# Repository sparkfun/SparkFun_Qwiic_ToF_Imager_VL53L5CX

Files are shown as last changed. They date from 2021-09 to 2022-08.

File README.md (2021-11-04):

SparkFun Qwiic ToF Imager with VL53L5CX
========================================

SparkFun Qwiic ToF Imager with VL53L5CX

[*SparkFun Qwiic ToF Imager with VL53L5CX(SEN-18642)*](https://www.sparkfun.com/products/18642)

The SparkFun Qwiic ToF Imager is built around VL53L5CX from ST Electronics; a state of the art, Time-of-Flight (ToF), multizone ranging sensor enhancing the ST FlightSense product family. This chip integrates a SPAD array, physical infrared filters, and diffractive optical elements (DOE) to achieve the best ranging performance in various ambient lighting conditions with a range of cover glass materials. Utilizing our handy Qwiic system, no soldering is required to connect it to the rest of your system. However, we still have broken out 0.1"-spaced pins in case you prefer to use a breadboard.

Multizone distance measurements are possible up to 8x8 zones with a wide 63° diagonal FoV which can be reduced by software. Thanks to ST Histogram patented algorithms, the VL53L5CX is able to detect different objects within the FoV. The Histogram also provides immunity to cover glass crosstalk beyond 60 cm.

Ideal for 3D room mapping, obstacle detection for robotics, gesture recognition, IoT, laser-assisted autofocus, and AR/VR enhancement, the Qwiic connector on this sensor makes integration easy. 

SparkFun labored with love to create this code. Feel like supporting open source hardware? 
Buy a [breakout board](https://www.sparkfun.com/products/14722) from SparkFun!

Repository Contents
-------------------

* **/Documents** - Datasheet and User Manual
* **/Hardware** - Eagle design files (.brd, .sch)

Documentation
--------------
* **[Arduino Library](https://github.com/sparkfun/SparkFun_VL53L5CX_Arduino_Library)** - Library for reading distance in millimeters, signal rate, status, etc.
* **[Hookup Guide](https://learn.sparkfun.com/tutorials/qwiic-tof-imager---vl53l5cx-hookup-guide)** - Hookup guide for the Qwiic ToF Imager VL53L5CX

License Information
-------------------

This product is _**open source**_! 

Please review the LICENSE.md file for license information. 

If you have any questions or concerns on licensing, please contact techsupport@sparkfun.com.

Please use, reuse, and modify these files as you see fit. Please maintain attribution to SparkFun Electronics and release any derivative under the same license.

Distributed as-is; no warranty is given.

- Your friends at SparkFun.

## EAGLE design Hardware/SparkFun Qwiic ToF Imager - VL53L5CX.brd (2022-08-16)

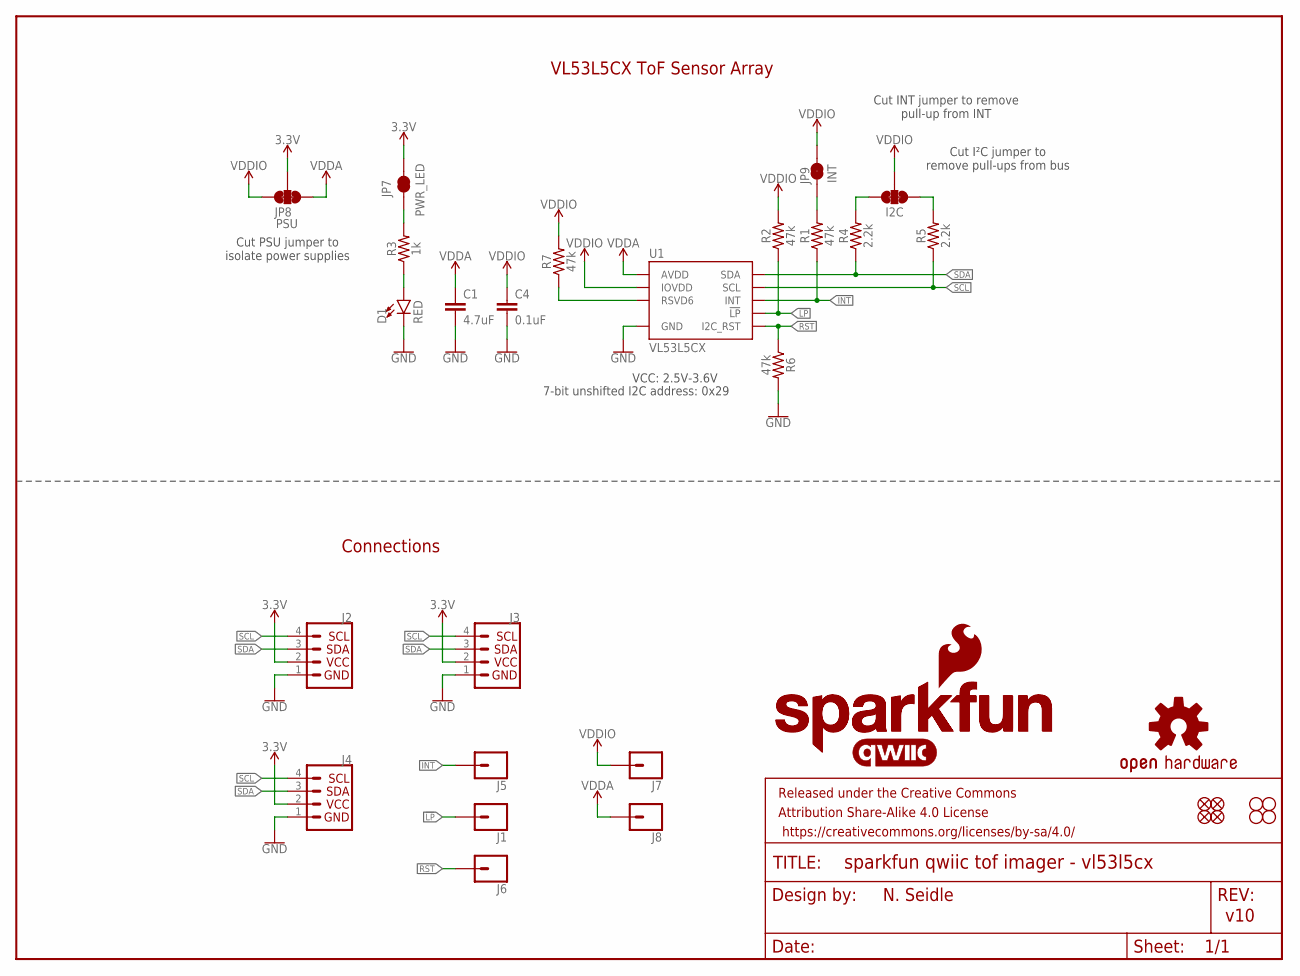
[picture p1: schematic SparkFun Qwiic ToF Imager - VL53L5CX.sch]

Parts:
C1: 4.7uF; 0603
C4: 0.1uF; 0603
D1: RED; LED-0603
FRAME1: FRAME-LETTER; CREATIVE_COMMONS
I2C: JUMPER-SMT_3_2-NC_TRACE_SILK; SMT-JUMPER_3_2-NC_TRACE_SILK
J1, J5, J6, J7, J8: CONN_01PTH_NO_SILK_YES_STOP; 1X01_NO_SILK
J2, J4: QWIIC_CONNECTORJS-1MM; JST04_1MM_RA
J3: PTH; 1X04_NO_SILK
JP1, JP2, JP5, JP6: FIDUCIALUFIDUCIAL; MICRO-FIDUCIAL
JP3, JP4, JP10, JP11: STAND-OFF
JP7: PWR_LED; SMT-JUMPER_2_NC_TRACE_SILK
JP8: PSU; SMT-JUMPER_3_2-NC_TRACE_SILK
JP9: INT; SMT-JUMPER_2_NC_TRACE_SILK
LOGO1: OSHW-LOGOMINI; OSHW-LOGO-MINI
LOGO3: QWIIC_LOGO_CONNECTOR; QWIIC_5.5MM
R1, R2, R6, R7: 47k; 0603
R3: 1k; 0603
R4, R5: 2.2k; 0603
U1: VL53L5CX
U$1: SFE_LOGO_NAME.1_INCH; SFE_LOGO_NAME_.1
U$2: SFE_LOGO_NAME_FLAME.1_INCH; SFE_LOGO_NAME_FLAME_.1

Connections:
3.3V: J2.2, J3.2 (VCC), J4.2, JP7.2, JP8.2
!LP: J1.1, R2.1, U1.A5 (!LP)
GND: C1.2, C4.2, D1.C, J2.1, J3.1 (GND), J4.1, R6.2, U1.A2 (GND), U1.A6 (GND), U1.A7 (GND), U1.B4 (GND), U1.C1 (GND), U1.C6 (GND), U1.C7 (GND)
INT: J5.1, R1.1, U1.A3 (INT)
unnamed: I2C.1, R5.2
unnamed: I2C.3, R4.2
unnamed: D1.A, R3.1
unnamed: JP9.1, R1.2
unnamed: JP7.1, R3.2
unnamed: R7.1, U1.C2 (RSVD6)
RST: J6.1, R6.1, U1.A1 (I2C_RST)
SCL: J2.4, J3.4 (SCL), J4.4, R5.1, U1.C4 (SCL)
SDA: J2.3, J3.3 (SDA), J4.3, R4.1, U1.C3 (SDA)
VDDA: C1.1, J8.1, JP8.1, U1.B1 (AVDD), U1.B7 (AVDD)
VDDIO: C4.1, I2C.2, J7.1, JP8.3, JP9.2, R2.2, R7.2, U1.A4 (IOVDD)

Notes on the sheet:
N. Seidle
v10
7-bit unshifted I2C address: 0x29
Cut I²C jumper to remove pull-ups from bus
Cut INT jumper to remove pull-up from INT
VCC: 2.5V-3.6V
VL53L5CX ToF Sensor Array
Cut PSU jumper to isolate power supplies
Connections

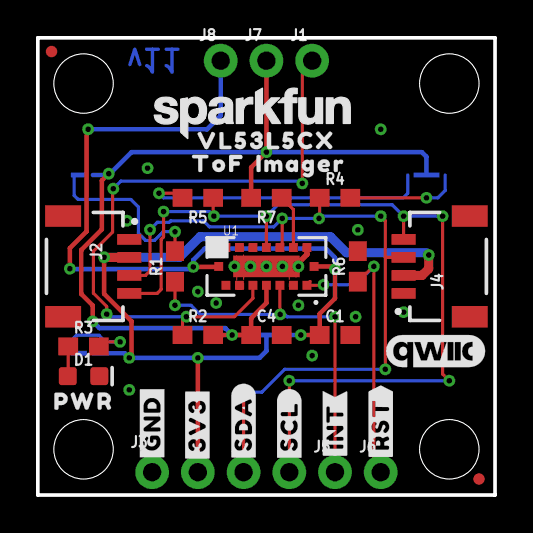
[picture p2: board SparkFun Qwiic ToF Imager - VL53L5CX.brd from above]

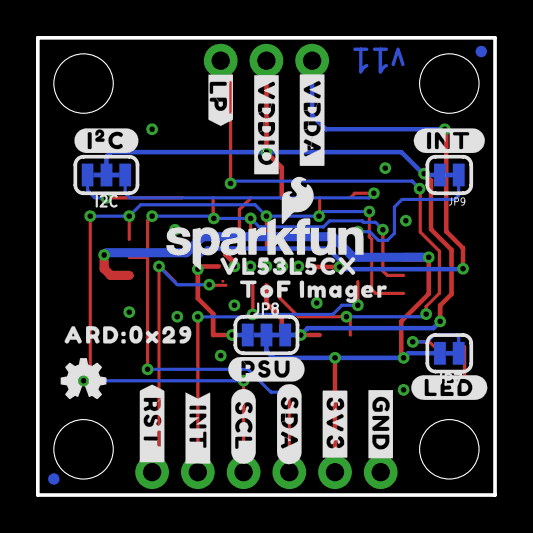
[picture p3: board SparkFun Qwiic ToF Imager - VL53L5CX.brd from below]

Board: 2 copper layers, 25.4 x 25.4 mm, 63 parts (25 on the bottom side), 15 nets.

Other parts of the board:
U$3, U$21: #3V3#13
U$4: PWR12
U$5: #LED#10
U$6: #INT#0
U$7: #RST#1
U$8: #INT_#0
U$9: #RST_#1
U$10: ##LP##2
U$11: #INT#1
U$12: #VDDA#0
U$14: #VDDIO#1
U$15: #PSU#0
U$16: #I�C#0
U$17, U$19: VL53L5CX0
U$18, U$22: IMAGER2
U$20, U$23: TOF1
U$24: #SCL#1
U$25: #SDA#0
U$26, U$30: #GND#62130
U$27: ARD#0X290
U$28: #SDA#62131
U$29: #SCL#62132

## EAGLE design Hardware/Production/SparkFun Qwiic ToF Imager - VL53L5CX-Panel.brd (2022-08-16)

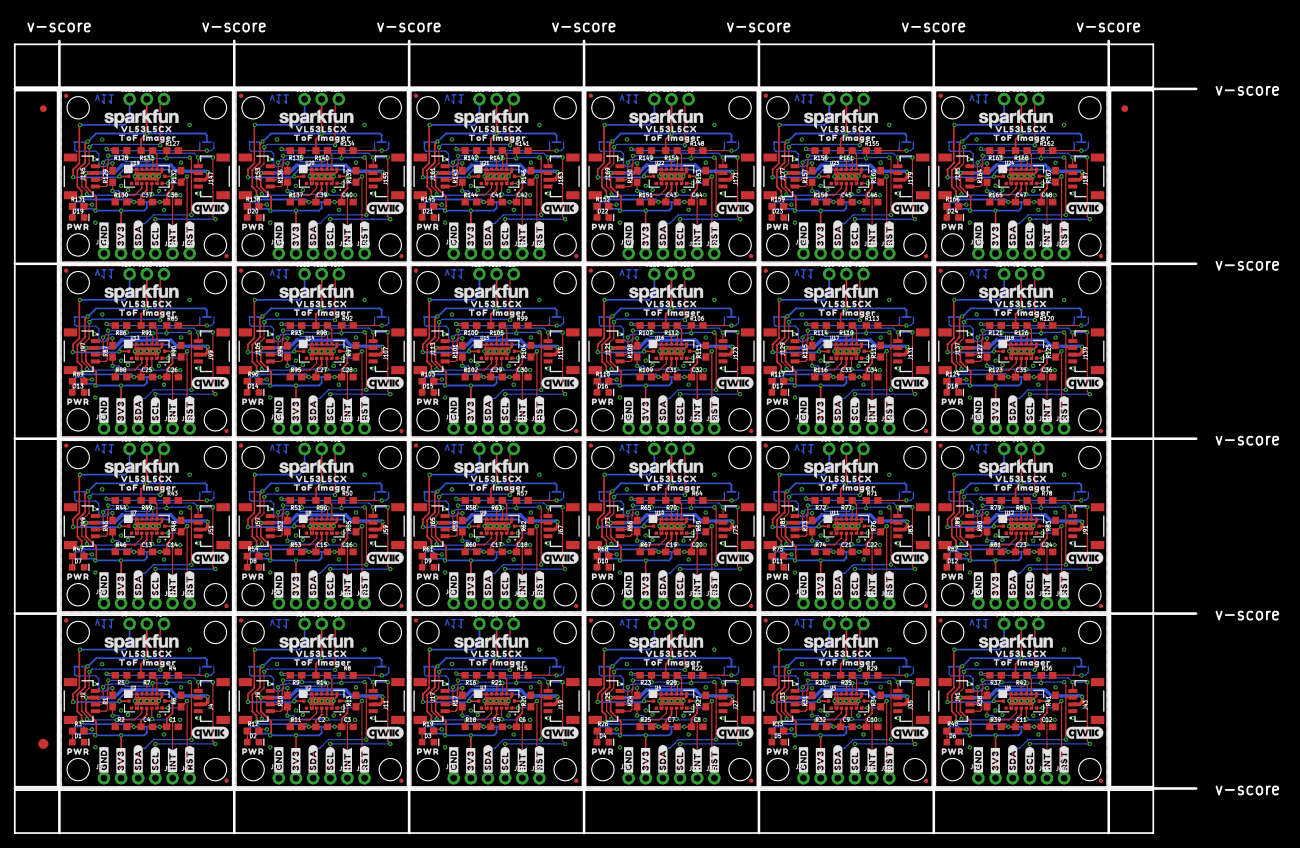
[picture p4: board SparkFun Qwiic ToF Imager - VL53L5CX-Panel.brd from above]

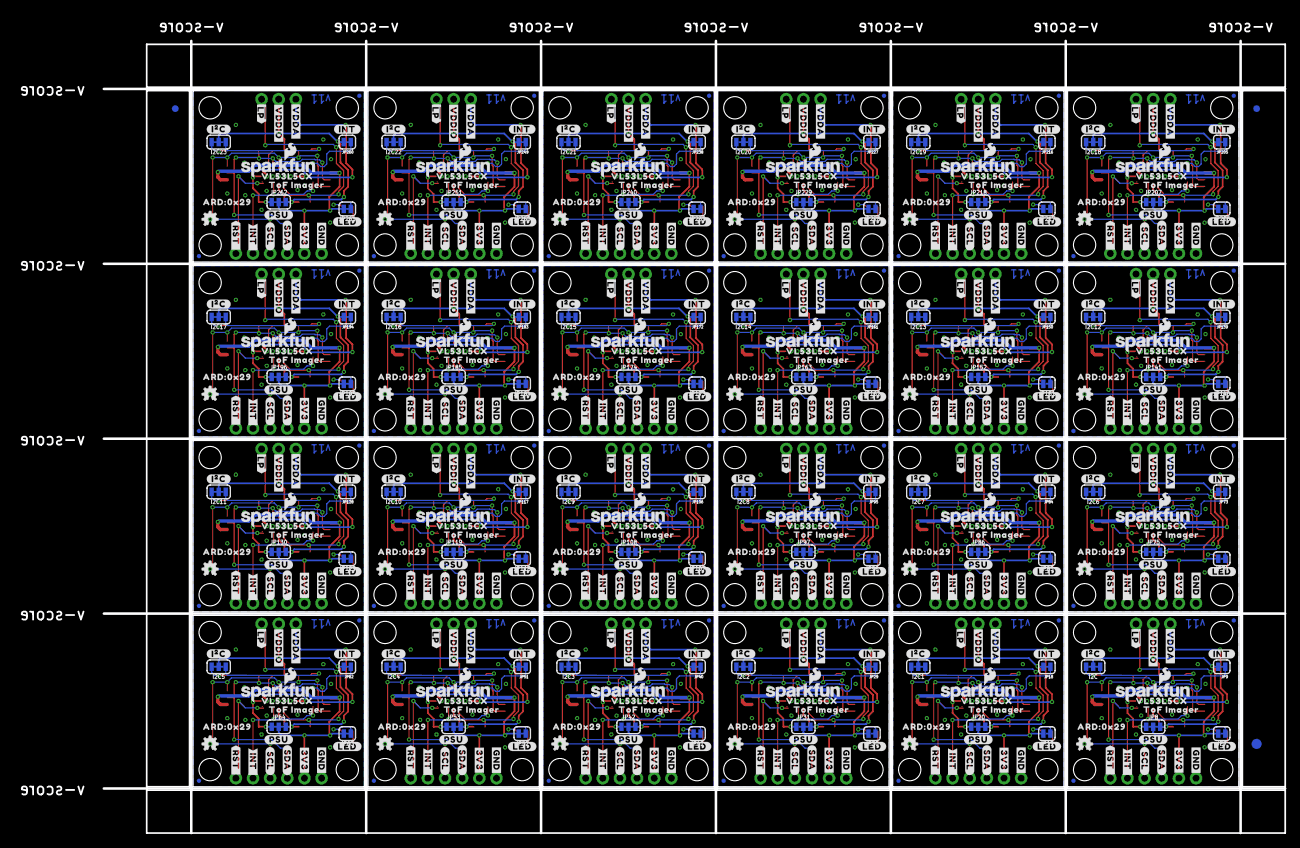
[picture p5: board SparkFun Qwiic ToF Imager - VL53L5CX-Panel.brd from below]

Board: 2 copper layers, 175.0 x 117.3 mm, 1494 parts (603 on the bottom side), 360 nets.

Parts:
C1, C3, C6, C8, C10, C12, C14, C16, C18, C20, C22, C24, C26, C28, C30, C32, C34, C36, C38, C40, C42, C44, C46, C48: 4.7uF; 0603
C2, C4, C5, C7, C9, C11, C13, C15, C17, C19, C21, C23, C25, C27, C29, C31, C33, C35, C37, C39, C41, C43, C45, C47: 0.1uF; 0603
D1, D2, D3, D4, D5, D6, D7, D8, D9, D10, D11, D12, D13, D14, D15, D16, D17, D18, D19, D20, D21, D22, D23, D24: RED; LED-0603
E$1, E$2, E$3, E$4: FIDUCIAL-1X2
E$5, E$6: FIDUCIAL-1.5X3
I2C, I2C1, I2C2, I2C3, I2C4, I2C5, I2C6, I2C7, I2C8, I2C9, I2C10, I2C11, I2C12, I2C13, I2C14, I2C15, I2C16, I2C17, I2C18, I2C19, I2C20, I2C21, I2C22, I2C23: JUMPER-SMT_3_2-NC_TRACE_SILK; SMT-JUMPER_3_2-NC_TRACE_SILK
J1, J5, J6, J7, J8, J12, J13, J14, J15, J16, J20, J21, J22, J23, J24, J28, J29, J30, J31, J32, J36, J37, J38, J39, J40, J44, J45, J46, J47, J48, J52, J53, J54, J55, J56, J60, J61, J62, J63, J64, J68, J69, J70, J71, J72, J76, J77, J78, J79, J80, J84, J85, J86, J87, J88, J92, J93, J94, J95, J96, J100, J101, J102, J103, J104, J108, J109, J110, J111, J112, J116, J117, J118, J119, J120, J124, J125, J126, J127, J128, J132, J133, J134, J135, J136, J140, J141, J142, J143, J144, J148, J149, J150, J151, J152, J156, J157, J158, J159, J160, J164, J165, J166, J167, J168, J172, J173, J174, J175, J176, J180, J181, J182, J183, J184, J188, J189, J190, J191, J192: 1X01_NO_SILK
J2, J4, J9, J11, J17, J19, J25, J27, J33, J35, J41, J43, J49, J51, J57, J59, J65, J67, J73, J75, J81, J83, J89, J91, J97, J99, J105, J107, J113, J115, J121, J123, J129, J131, J137, J139, J145, J147, J153, J155, J161, J163, J169, J171, J177, J179, J185, J187: JST04_1MM_RA
J3, J10, J18, J26, J34, J42, J50, J58, J66, J74, J82, J90, J98, J106, J114, J122, J130, J138, J146, J154, J162, J170, J178, J186: PTH; 1X04_NO_SILK
JP1, JP2, JP5, JP6, JP14, JP15, JP16, JP17, JP25, JP26, JP27, JP28, JP36, JP37, JP38, JP39, JP47, JP48, JP49, JP50, JP58, JP59, JP60, JP61, JP69, JP70, JP71, JP72, JP80, JP81, JP82, JP83, JP91, JP92, JP93, JP94, JP102, JP103, JP104, JP105, JP113, JP114, JP115, JP116, JP124, JP125, JP126, JP127, JP135, JP136, JP137, JP138, JP146, JP147, JP148, JP149, JP157, JP158, JP159, JP160, JP168, JP169, JP170, JP171, JP179, JP180, JP181, JP182, JP190, JP191, JP192, JP193, JP201, JP202, JP203, JP204, JP212, JP213, JP214, JP215, JP223, JP224, JP225, JP226, JP234, JP235, JP236, JP237, JP245, JP246, JP247, JP248, JP256, JP257, JP258, JP259: FIDUCIALUFIDUCIAL; MICRO-FIDUCIAL
JP3, JP4, JP10, JP11, JP12, JP13, JP21, JP22, JP23, JP24, JP32, JP33, JP34, JP35, JP43, JP44, JP45, JP46, JP54, JP55, JP56, JP57, JP65, JP66, JP67, JP68, JP76, JP77, JP78, JP79, JP87, JP88, JP89, JP90, JP98, JP99, JP100, JP101, JP109, JP110, JP111, JP112, JP120, JP121, JP122, JP123, JP131, JP132, JP133, JP134, JP142, JP143, JP144, JP145, JP153, JP154, JP155, JP156, JP164, JP165, JP166, JP167, JP175, JP176, JP177, JP178, JP186, JP187, JP188, JP189, JP197, JP198, JP199, JP200, JP208, JP209, JP210, JP211, JP219, JP220, JP221, JP222, JP230, JP231, JP232, JP233, JP241, JP242, JP243, JP244, JP252, JP253, JP254, JP255, JP263, JP264: STAND-OFF
JP7, JP19, JP30, JP41, JP52, JP63, JP74, JP85, JP96, JP107, JP118, JP129, JP140, JP151, JP162, JP173, JP184, JP195, JP206, JP217, JP228, JP239, JP250, JP261: PWR_LED; SMT-JUMPER_2_NC_TRACE_SILK
JP8, JP20, JP31, JP42, JP53, JP64, JP75, JP86, JP97, JP108, JP119, JP130, JP141, JP152, JP163, JP174, JP185, JP196, JP207, JP218, JP229, JP240, JP251, JP262: PSU; SMT-JUMPER_3_2-NC_TRACE_SILK
JP9, JP18, JP29, JP40, JP51, JP62, JP73, JP84, JP95, JP106, JP117, JP128, JP139, JP150, JP161, JP172, JP183, JP194, JP205, JP216, JP227, JP238, JP249, JP260: INT; SMT-JUMPER_2_NC_TRACE_SILK
LOGO1, LOGO2, LOGO5, LOGO7, LOGO9, LOGO11, LOGO13, LOGO15, LOGO17, LOGO19, LOGO21, LOGO23, LOGO25, LOGO27, LOGO29, LOGO31, LOGO33, LOGO35, LOGO37, LOGO39, LOGO41, LOGO43, LOGO45, LOGO47: OSHW-LOGOMINI; OSHW-LOGO-MINI
LOGO3, LOGO4, LOGO6, LOGO8, LOGO10, LOGO12, LOGO14, LOGO16, LOGO18, LOGO20, LOGO22, LOGO24, LOGO26, LOGO28, LOGO30, LOGO32, LOGO34, LOGO36, LOGO38, LOGO40, LOGO42, LOGO44, LOGO46, LOGO48: QWIIC_LOGO_CONNECTOR; QWIIC_5.5MM
R1, R2, R6, R7, R10, R11, R13, R14, R17, R18, R20, R21, R24, R25, R27, R28, R31, R32, R34, R35, R38, R39, R41, R42, R45, R46, R48, R49, R52, R53, R55, R56, R59, R60, R62, R63, R66, R67, R69, R70, R73, R74, R76, R77, R80, R81, R83, R84, R87, R88, R90, R91, R94, R95, R97, R98, R101, R102, R104, R105, R108, R109, R111, R112, R115, R116, R118, R119, R122, R123, R125, R126, R129, R130, R132, R133, R136, R137, R139, R140, R143, R144, R146, R147, R150, R151, R153, R154, R157, R158, R160, R161, R164, R165, R167, R168: 47k; 0603
R3, R12, R19, R26, R33, R40, R47, R54, R61, R68, R75, R82, R89, R96, R103, R110, R117, R124, R131, R138, R145, R152, R159, R166: 1k; 0603
R4, R5, R8, R9, R15, R16, R22, R23, R29, R30, R36, R37, R43, R44, R50, R51, R57, R58, R64, R65, R71, R72, R78, R79, R85, R86, R92, R93, R99, R100, R106, R107, R113, R114, R120, R121, R127, R128, R134, R135, R141, R142, R148, R149, R155, R156, R162, R163: 2.2k; 0603
U1, U2, U3, U4, U5, U6, U7, U8, U9, U10, U11, U12, U13, U14, U15, U16, U17, U18, U19, U20, U21, U22, U23, U24: VL53L5CX
U$1, U$31, U$60, U$89, U$118, U$147, U$176, U$205, U$234, U$263, U$292, U$321, U$350, U$379, U$408, U$437, U$466, U$495, U$524, U$553, U$582, U$611, U$640, U$669: SFE_LOGO_NAME.1_INCH; SFE_LOGO_NAME_.1
U$2, U$13, U$59, U$88, U$117, U$146, U$175, U$204, U$233, U$262, U$291, U$320, U$349, U$378, U$407, U$436, U$465, U$494, U$523, U$552, U$581, U$610, U$639, U$668: SFE_LOGO_NAME_FLAME.1_INCH; SFE_LOGO_NAME_FLAME_.1
U$3, U$21, U$36, U$37, U$65, U$66, U$94, U$95, U$123, U$124, U$152, U$153, U$181, U$182, U$210, U$211, U$239, U$240, U$268, U$269, U$297, U$298, U$326, U$327, U$355, U$356, U$384, U$385, U$413, U$414, U$442, U$443, U$471, U$472, U$500, U$501, U$529, U$530, U$558, U$559, U$587, U$588, U$616, U$617, U$645, U$646, U$674, U$675: #3V3#13
U$4, U$38, U$67, U$96, U$125, U$154, U$183, U$212, U$241, U$270, U$299, U$328, U$357, U$386, U$415, U$444, U$473, U$502, U$531, U$560, U$589, U$618, U$647, U$676: PWR12
U$5, U$39, U$68, U$97, U$126, U$155, U$184, U$213, U$242, U$271, U$300, U$329, U$358, U$387, U$416, U$445, U$474, U$503, U$532, U$561, U$590, U$619, U$648, U$677: #LED#10
U$6, U$40, U$69, U$98, U$127, U$156, U$185, U$214, U$243, U$272, U$301, U$330, U$359, U$388, U$417, U$446, U$475, U$504, U$533, U$562, U$591, U$620, U$649, U$678: #INT#0
U$7, U$41, U$70, U$99, U$128, U$157, U$186, U$215, U$244, U$273, U$302, U$331, U$360, U$389, U$418, U$447, U$476, U$505, U$534, U$563, U$592, U$621, U$650, U$679: #RST#1
U$8, U$42, U$71, U$100, U$129, U$158, U$187, U$216, U$245, U$274, U$303, U$332, U$361, U$390, U$419, U$448, U$477, U$506, U$535, U$564, U$593, U$622, U$651, U$680: #INT_#0
U$9, U$43, U$72, U$101, U$130, U$159, U$188, U$217, U$246, U$275, U$304, U$333, U$362, U$391, U$420, U$449, U$478, U$507, U$536, U$565, U$594, U$623, U$652, U$681: #RST_#1
U$10, U$44, U$73, U$102, U$131, U$160, U$189, U$218, U$247, U$276, U$305, U$334, U$363, U$392, U$421, U$450, U$479, U$508, U$537, U$566, U$595, U$624, U$653, U$682: ##LP##2
U$11, U$51, U$80, U$109, U$138, U$167, U$196, U$225, U$254, U$283, U$312, U$341, U$370, U$399, U$428, U$457, U$486, U$515, U$544, U$573, U$602, U$631, U$660, U$689: #INT#1
U$12, U$45, U$74, U$103, U$132, U$161, U$190, U$219, U$248, U$277, U$306, U$335, U$364, U$393, U$422, U$451, U$480, U$509, U$538, U$567, U$596, U$625, U$654, U$683: #VDDA#0
U$14, U$46, U$75, U$104, U$133, U$162, U$191, U$220, U$249, U$278, U$307, U$336, U$365, U$394, U$423, U$452, U$481, U$510, U$539, U$568, U$597, U$626, U$655, U$684: #VDDIO#1
U$15, U$52, U$81, U$110, U$139, U$168, U$197, U$226, U$255, U$284, U$313, U$342, U$371, U$400, U$429, U$458, U$487, U$516, U$545, U$574, U$603, U$632, U$661, U$690: #PSU#0
U$16, U$50, U$79, U$108, U$137, U$166, U$195, U$224, U$253, U$282, U$311, U$340, U$369, U$398, U$427, U$456, U$485, U$514, U$543, U$572, U$601, U$630, U$659, U$688: #I�C#0
U$17, U$19, U$47, U$53, U$76, U$82, U$105, U$111, U$134, U$140, U$163, U$169, U$192, U$198, U$221, U$227, U$250, U$256, U$279, U$285, U$308, U$314, U$337, U$343, U$366, U$372, U$395, U$401, U$424, U$430, U$453, U$459, U$482, U$488, U$511, U$517, U$540, U$546, U$569, U$575, U$598, U$604, U$627, U$633, U$656, U$662, U$685, U$691: VL53L5CX0
U$18, U$22, U$48, U$55, U$77, U$84, U$106, U$113, U$135, U$142, U$164, U$171, U$193, U$200, U$222, U$229, U$251, U$258, U$280, U$287, U$309, U$316, U$338, U$345, U$367, U$374, U$396, U$403, U$425, U$432, U$454, U$461, U$483, U$490, U$512, U$519, U$541, U$548, U$570, U$577, U$599, U$606, U$628, U$635, U$657, U$664, U$686, U$693: IMAGER2
U$20, U$23, U$49, U$54, U$78, U$83, U$107, U$112, U$136, U$141, U$165, U$170, U$194, U$199, U$223, U$228, U$252, U$257, U$281, U$286, U$310, U$315, U$339, U$344, U$368, U$373, U$397, U$402, U$426, U$431, U$455, U$460, U$484, U$489, U$513, U$518, U$542, U$547, U$571, U$576, U$600, U$605, U$629, U$634, U$658, U$663, U$687, U$692: TOF1
U$24, U$56, U$85, U$114, U$143, U$172, U$201, U$230, U$259, U$288, U$317, U$346, U$375, U$404, U$433, U$462, U$491, U$520, U$549, U$578, U$607, U$636, U$665, U$694: #SCL#1
U$25, U$57, U$86, U$115, U$144, U$173, U$202, U$231, U$260, U$289, U$318, U$347, U$376, U$405, U$434, U$463, U$492, U$521, U$550, U$579, U$608, U$637, U$666, U$695: #SDA#0
U$26, U$30, U$32, U$35, U$61, U$64, U$90, U$93, U$119, U$122, U$148, U$151, U$177, U$180, U$206, U$209, U$235, U$238, U$264, U$267, U$293, U$296, U$322, U$325, U$351, U$354, U$380, U$383, U$409, U$412, U$438, U$441, U$467, U$470, U$496, U$499, U$525, U$528, U$554, U$557, U$583, U$586, U$612, U$615, U$641, U$644, U$670, U$673: #GND#62130
U$27, U$58, U$87, U$116, U$145, U$174, U$203, U$232, U$261, U$290, U$319, U$348, U$377, U$406, U$435, U$464, U$493, U$522, U$551, U$580, U$609, U$638, U$667, U$696: ARD#0X290
U$28, U$33, U$62, U$91, U$120, U$149, U$178, U$207, U$236, U$265, U$294, U$323, U$352, U$381, U$410, U$439, U$468, U$497, U$526, U$555, U$584, U$613, U$642, U$671: #SDA#62131
U$29, U$34, U$63, U$92, U$121, U$150, U$179, U$208, U$237, U$266, U$295, U$324, U$353, U$382, U$411, U$440, U$469, U$498, U$527, U$556, U$585, U$614, U$643, U$672: #SCL#62132

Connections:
3.3V: J2.2, J3.2, J4.2, JP7.2, JP8.2
3.3V1: J9.2, J10.2, J11.2, JP19.2, JP20.2
3.3V2: J17.2, J18.2, J19.2, JP30.2, JP31.2
3.3V3: J25.2, J26.2, J27.2, JP41.2, JP42.2
3.3V4: J33.2, J34.2, J35.2, JP52.2, JP53.2
3.3V5: J41.2, J42.2, J43.2, JP63.2, JP64.2
3.3V6: J49.2, J50.2, J51.2, JP74.2, JP75.2
3.3V7: J57.2, J58.2, J59.2, JP85.2, JP86.2
3.3V8: J65.2, J66.2, J67.2, JP96.2, JP97.2
3.3V9: J73.2, J74.2, J75.2, JP107.2, JP108.2
3.3V10: J81.2, J82.2, J83.2, JP118.2, JP119.2
3.3V11: J89.2, J90.2, J91.2, JP129.2, JP130.2
3.3V12: J97.2, J98.2, J99.2, JP140.2, JP141.2
3.3V13: J105.2, J106.2, J107.2, JP151.2, JP152.2
3.3V14: J113.2, J114.2, J115.2, JP162.2, JP163.2
3.3V15: J121.2, J122.2, J123.2, JP173.2, JP174.2
3.3V16: J129.2, J130.2, J131.2, JP184.2, JP185.2
3.3V17: J137.2, J138.2, J139.2, JP195.2, JP196.2
3.3V18: J145.2, J146.2, J147.2, JP206.2, JP207.2
3.3V19: J153.2, J154.2, J155.2, JP217.2, JP218.2
3.3V20: J161.2, J162.2, J163.2, JP228.2, JP229.2
3.3V21: J169.2, J170.2, J171.2, JP239.2, JP240.2
3.3V22: J177.2, J178.2, J179.2, JP250.2, JP251.2
3.3V23: J185.2, J186.2, J187.2, JP261.2, JP262.2
!LP: J1.1, R2.1, U1.A5
!LP1: J13.1, R11.1, U2.A5
!LP2: J21.1, R18.1, U3.A5
!LP3: J29.1, R25.1, U4.A5
!LP4: J37.1, R32.1, U5.A5
!LP5: J45.1, R39.1, U6.A5
!LP6: J53.1, R46.1, U7.A5
!LP7: J61.1, R53.1, U8.A5
!LP8: J69.1, R60.1, U9.A5
!LP9: J77.1, R67.1, U10.A5
!LP10: J85.1, R74.1, U11.A5
!LP11: J93.1, R81.1, U12.A5
!LP12: J101.1, R88.1, U13.A5
!LP13: J109.1, R95.1, U14.A5
!LP14: J117.1, R102.1, U15.A5
!LP15: J125.1, R109.1, U16.A5
!LP16: J133.1, R116.1, U17.A5
!LP17: J141.1, R123.1, U18.A5
!LP18: J149.1, R130.1, U19.A5
!LP19: J157.1, R137.1, U20.A5
!LP20: J165.1, R144.1, U21.A5
!LP21: J173.1, R151.1, U22.A5
!LP22: J181.1, R158.1, U23.A5
!LP23: J189.1, R165.1, U24.A5
GND: C1.2, C4.2, D1.C, J2.1, J3.1, J4.1, R6.2, U1.A2, U1.A6, U1.A7, U1.B4, U1.C1, U1.C6, U1.C7
GND1: C2.2, C3.2, D2.C, J9.1, J10.1, J11.1, R13.2, U2.A2, U2.A6, U2.A7, U2.B4, U2.C1, U2.C6, U2.C7
GND2: C5.2, C6.2, D3.C, J17.1, J18.1, J19.1, R20.2, U3.A2, U3.A6, U3.A7, U3.B4, U3.C1, U3.C6, U3.C7
GND3: C7.2, C8.2, D4.C, J25.1, J26.1, J27.1, R27.2, U4.A2, U4.A6, U4.A7, U4.B4, U4.C1, U4.C6, U4.C7
GND4: C9.2, C10.2, D5.C, J33.1, J34.1, J35.1, R34.2, U5.A2, U5.A6, U5.A7, U5.B4, U5.C1, U5.C6, U5.C7
GND5: C11.2, C12.2, D6.C, J41.1, J42.1, J43.1, R41.2, U6.A2, U6.A6, U6.A7, U6.B4, U6.C1, U6.C6, U6.C7
GND6: C13.2, C14.2, D7.C, J49.1, J50.1, J51.1, R48.2, U7.A2, U7.A6, U7.A7, U7.B4, U7.C1, U7.C6, U7.C7
GND7: C15.2, C16.2, D8.C, J57.1, J58.1, J59.1, R55.2, U8.A2, U8.A6, U8.A7, U8.B4, U8.C1, U8.C6, U8.C7
GND8: C17.2, C18.2, D9.C, J65.1, J66.1, J67.1, R62.2, U9.A2, U9.A6, U9.A7, U9.B4, U9.C1, U9.C6, U9.C7
GND9: C19.2, C20.2, D10.C, J73.1, J74.1, J75.1, R69.2, U10.A2, U10.A6, U10.A7, U10.B4, U10.C1, U10.C6, U10.C7
GND10: C21.2, C22.2, D11.C, J81.1, J82.1, J83.1, R76.2, U11.A2, U11.A6, U11.A7, U11.B4, U11.C1, U11.C6, U11.C7
GND11: C23.2, C24.2, D12.C, J89.1, J90.1, J91.1, R83.2, U12.A2, U12.A6, U12.A7, U12.B4, U12.C1, U12.C6, U12.C7
GND12: C25.2, C26.2, D13.C, J97.1, J98.1, J99.1, R90.2, U13.A2, U13.A6, U13.A7, U13.B4, U13.C1, U13.C6, U13.C7
GND13: C27.2, C28.2, D14.C, J105.1, J106.1, J107.1, R97.2, U14.A2, U14.A6, U14.A7, U14.B4, U14.C1, U14.C6, U14.C7
GND14: C29.2, C30.2, D15.C, J113.1, J114.1, J115.1, R104.2, U15.A2, U15.A6, U15.A7, U15.B4, U15.C1, U15.C6, U15.C7
GND15: C31.2, C32.2, D16.C, J121.1, J122.1, J123.1, R111.2, U16.A2, U16.A6, U16.A7, U16.B4, U16.C1, U16.C6, U16.C7
GND16: C33.2, C34.2, D17.C, J129.1, J130.1, J131.1, R118.2, U17.A2, U17.A6, U17.A7, U17.B4, U17.C1, U17.C6, U17.C7
GND17: C35.2, C36.2, D18.C, J137.1, J138.1, J139.1, R125.2, U18.A2, U18.A6, U18.A7, U18.B4, U18.C1, U18.C6, U18.C7
GND18: C37.2, C38.2, D19.C, J145.1, J146.1, J147.1, R132.2, U19.A2, U19.A6, U19.A7, U19.B4, U19.C1, U19.C6, U19.C7
GND19: C39.2, C40.2, D20.C, J153.1, J154.1, J155.1, R139.2, U20.A2, U20.A6, U20.A7, U20.B4, U20.C1, U20.C6, U20.C7
GND20: C41.2, C42.2, D21.C, J161.1, J162.1, J163.1, R146.2, U21.A2, U21.A6, U21.A7, U21.B4, U21.C1, U21.C6, U21.C7
GND21: C43.2, C44.2, D22.C, J169.1, J170.1, J171.1, R153.2, U22.A2, U22.A6, U22.A7, U22.B4, U22.C1, U22.C6, U22.C7
GND22: C45.2, C46.2, D23.C, J177.1, J178.1, J179.1, R160.2, U23.A2, U23.A6, U23.A7, U23.B4, U23.C1, U23.C6, U23.C7
GND23: C47.2, C48.2, D24.C, J185.1, J186.1, J187.1, R167.2, U24.A2, U24.A6, U24.A7, U24.B4, U24.C1, U24.C6, U24.C7
INT: J5.1, R1.1, U1.A3
INT1: J12.1, R10.1, U2.A3
INT2: J20.1, R17.1, U3.A3
INT3: J28.1, R24.1, U4.A3
INT4: J36.1, R31.1, U5.A3
INT5: J44.1, R38.1, U6.A3
INT6: J52.1, R45.1, U7.A3
INT7: J60.1, R52.1, U8.A3
INT8: J68.1, R59.1, U9.A3
INT9: J76.1, R66.1, U10.A3
INT10: J84.1, R73.1, U11.A3
INT11: J92.1, R80.1, U12.A3
INT12: J100.1, R87.1, U13.A3
INT13: J108.1, R94.1, U14.A3
INT14: J116.1, R101.1, U15.A3
INT15: J124.1, R108.1, U16.A3
INT16: J132.1, R115.1, U17.A3
INT17: J140.1, R122.1, U18.A3
INT18: J148.1, R129.1, U19.A3
INT19: J156.1, R136.1, U20.A3
INT20: J164.1, R143.1, U21.A3
INT21: J172.1, R150.1, U22.A3
INT22: J180.1, R157.1, U23.A3
INT23: J188.1, R164.1, U24.A3
unnamed: I2C.1, R5.2
unnamed: I2C.3, R4.2
unnamed: D1.A, R3.1
unnamed: JP9.1, R1.2
unnamed: JP7.1, R3.2
unnamed: R7.1, U1.C2
unnamed: I2C1.1, R9.2
unnamed: I2C1.3, R8.2
unnamed: JP18.1, R10.2
unnamed: D2.A, R12.1
unnamed: JP19.1, R12.2
unnamed: R14.1, U2.C2
unnamed: I2C2.1, R16.2
unnamed: I2C2.3, R15.2
unnamed: JP29.1, R17.2
unnamed: D3.A, R19.1
unnamed: JP30.1, R19.2
unnamed: R21.1, U3.C2
unnamed: I2C3.1, R23.2
unnamed: I2C3.3, R22.2
unnamed: JP40.1, R24.2
unnamed: D4.A, R26.1
unnamed: JP41.1, R26.2
unnamed: R28.1, U4.C2
unnamed: I2C4.1, R30.2
unnamed: I2C4.3, R29.2
unnamed: JP51.1, R31.2
unnamed: D5.A, R33.1
unnamed: JP52.1, R33.2
unnamed: R35.1, U5.C2
unnamed: I2C5.1, R37.2
unnamed: I2C5.3, R36.2
unnamed: JP62.1, R38.2
unnamed: D6.A, R40.1
unnamed: JP63.1, R40.2
unnamed: R42.1, U6.C2
unnamed: I2C6.1, R44.2
unnamed: I2C6.3, R43.2
unnamed: JP73.1, R45.2
unnamed: D7.A, R47.1
unnamed: JP74.1, R47.2
unnamed: R49.1, U7.C2
unnamed: I2C7.1, R51.2
unnamed: I2C7.3, R50.2
unnamed: JP84.1, R52.2
unnamed: D8.A, R54.1
unnamed: JP85.1, R54.2
unnamed: R56.1, U8.C2
unnamed: I2C8.1, R58.2
unnamed: I2C8.3, R57.2
unnamed: JP95.1, R59.2
unnamed: D9.A, R61.1
unnamed: JP96.1, R61.2
unnamed: R63.1, U9.C2
unnamed: I2C9.1, R65.2
unnamed: I2C9.3, R64.2
unnamed: JP106.1, R66.2
unnamed: D10.A, R68.1
unnamed: JP107.1, R68.2
unnamed: R70.1, U10.C2
unnamed: I2C10.1, R72.2
unnamed: I2C10.3, R71.2
unnamed: JP117.1, R73.2
unnamed: D11.A, R75.1
unnamed: JP118.1, R75.2
unnamed: R77.1, U11.C2
unnamed: I2C11.1, R79.2
unnamed: I2C11.3, R78.2
unnamed: JP128.1, R80.2
unnamed: D12.A, R82.1
unnamed: JP129.1, R82.2
unnamed: R84.1, U12.C2
unnamed: I2C12.1, R86.2
unnamed: I2C12.3, R85.2
unnamed: JP139.1, R87.2
unnamed: D13.A, R89.1
unnamed: JP140.1, R89.2
unnamed: R91.1, U13.C2
unnamed: I2C13.1, R93.2
unnamed: I2C13.3, R92.2
unnamed: JP150.1, R94.2
unnamed: D14.A, R96.1
unnamed: JP151.1, R96.2
unnamed: R98.1, U14.C2
unnamed: I2C14.1, R100.2
unnamed: I2C14.3, R99.2
unnamed: JP161.1, R101.2
unnamed: D15.A, R103.1
unnamed: JP162.1, R103.2
unnamed: R105.1, U15.C2
unnamed: I2C15.1, R107.2
unnamed: I2C15.3, R106.2
unnamed: JP172.1, R108.2
unnamed: D16.A, R110.1
unnamed: JP173.1, R110.2
unnamed: R112.1, U16.C2
unnamed: I2C16.1, R114.2
unnamed: I2C16.3, R113.2
unnamed: JP183.1, R115.2
unnamed: D17.A, R117.1
unnamed: JP184.1, R117.2
unnamed: R119.1, U17.C2
unnamed: I2C17.1, R121.2
unnamed: I2C17.3, R120.2
unnamed: JP194.1, R122.2
unnamed: D18.A, R124.1
unnamed: JP195.1, R124.2
unnamed: R126.1, U18.C2
unnamed: I2C18.1, R128.2
unnamed: I2C18.3, R127.2
unnamed: JP205.1, R129.2
unnamed: D19.A, R131.1
unnamed: JP206.1, R131.2
unnamed: R133.1, U19.C2
unnamed: I2C19.1, R135.2
unnamed: I2C19.3, R134.2
unnamed: JP216.1, R136.2
unnamed: D20.A, R138.1
unnamed: JP217.1, R138.2
unnamed: R140.1, U20.C2
unnamed: I2C20.1, R142.2
unnamed: I2C20.3, R141.2
unnamed: JP227.1, R143.2
unnamed: D21.A, R145.1
unnamed: JP228.1, R145.2
unnamed: R147.1, U21.C2
unnamed: I2C21.1, R149.2
unnamed: I2C21.3, R148.2
unnamed: JP238.1, R150.2
unnamed: D22.A, R152.1
unnamed: JP239.1, R152.2
unnamed: R154.1, U22.C2
unnamed: I2C22.1, R156.2
unnamed: I2C22.3, R155.2
unnamed: JP249.1, R157.2
unnamed: D23.A, R159.1
unnamed: JP250.1, R159.2
unnamed: R161.1, U23.C2
unnamed: I2C23.1, R163.2
unnamed: I2C23.3, R162.2
unnamed: JP260.1, R164.2
unnamed: D24.A, R166.1
unnamed: JP261.1, R166.2
unnamed: R168.1, U24.C2
RST: J6.1, R6.1, U1.A1
RST1: J14.1, R13.1, U2.A1
RST2: J22.1, R20.1, U3.A1
RST3: J30.1, R27.1, U4.A1
RST4: J38.1, R34.1, U5.A1
RST5: J46.1, R41.1, U6.A1
RST6: J54.1, R48.1, U7.A1
RST7: J62.1, R55.1, U8.A1
RST8: J70.1, R62.1, U9.A1
RST9: J78.1, R69.1, U10.A1
RST10: J86.1, R76.1, U11.A1
RST11: J94.1, R83.1, U12.A1
RST12: J102.1, R90.1, U13.A1
RST13: J110.1, R97.1, U14.A1
RST14: J118.1, R104.1, U15.A1
RST15: J126.1, R111.1, U16.A1
RST16: J134.1, R118.1, U17.A1
RST17: J142.1, R125.1, U18.A1
RST18: J150.1, R132.1, U19.A1
RST19: J158.1, R139.1, U20.A1
RST20: J166.1, R146.1, U21.A1
RST21: J174.1, R153.1, U22.A1
RST22: J182.1, R160.1, U23.A1
RST23: J190.1, R167.1, U24.A1
SCL: J2.4, J3.4, J4.4, R5.1, U1.C4
SCL1: J9.4, J10.4, J11.4, R9.1, U2.C4
SCL2: J17.4, J18.4, J19.4, R16.1, U3.C4
SCL3: J25.4, J26.4, J27.4, R23.1, U4.C4
SCL4: J33.4, J34.4, J35.4, R30.1, U5.C4
SCL5: J41.4, J42.4, J43.4, R37.1, U6.C4
SCL6: J49.4, J50.4, J51.4, R44.1, U7.C4
SCL7: J57.4, J58.4, J59.4, R51.1, U8.C4
SCL8: J65.4, J66.4, J67.4, R58.1, U9.C4
SCL9: J73.4, J74.4, J75.4, R65.1, U10.C4
SCL10: J81.4, J82.4, J83.4, R72.1, U11.C4
SCL11: J89.4, J90.4, J91.4, R79.1, U12.C4
SCL12: J97.4, J98.4, J99.4, R86.1, U13.C4
SCL13: J105.4, J106.4, J107.4, R93.1, U14.C4
SCL14: J113.4, J114.4, J115.4, R100.1, U15.C4
SCL15: J121.4, J122.4, J123.4, R107.1, U16.C4
SCL16: J129.4, J130.4, J131.4, R114.1, U17.C4
SCL17: J137.4, J138.4, J139.4, R121.1, U18.C4
SCL18: J145.4, J146.4, J147.4, R128.1, U19.C4
SCL19: J153.4, J154.4, J155.4, R135.1, U20.C4
SCL20: J161.4, J162.4, J163.4, R142.1, U21.C4
SCL21: J169.4, J170.4, J171.4, R149.1, U22.C4
SCL22: J177.4, J178.4, J179.4, R156.1, U23.C4
SCL23: J185.4, J186.4, J187.4, R163.1, U24.C4
SDA: J2.3, J3.3, J4.3, R4.1, U1.C3
SDA1: J9.3, J10.3, J11.3, R8.1, U2.C3
SDA2: J17.3, J18.3, J19.3, R15.1, U3.C3
SDA3: J25.3, J26.3, J27.3, R22.1, U4.C3
SDA4: J33.3, J34.3, J35.3, R29.1, U5.C3
SDA5: J41.3, J42.3, J43.3, R36.1, U6.C3
SDA6: J49.3, J50.3, J51.3, R43.1, U7.C3
SDA7: J57.3, J58.3, J59.3, R50.1, U8.C3
SDA8: J65.3, J66.3, J67.3, R57.1, U9.C3
SDA9: J73.3, J74.3, J75.3, R64.1, U10.C3
SDA10: J81.3, J82.3, J83.3, R71.1, U11.C3
SDA11: J89.3, J90.3, J91.3, R78.1, U12.C3
SDA12: J97.3, J98.3, J99.3, R85.1, U13.C3
SDA13: J105.3, J106.3, J107.3, R92.1, U14.C3
SDA14: J113.3, J114.3, J115.3, R99.1, U15.C3
SDA15: J121.3, J122.3, J123.3, R106.1, U16.C3
SDA16: J129.3, J130.3, J131.3, R113.1, U17.C3
SDA17: J137.3, J138.3, J139.3, R120.1, U18.C3
SDA18: J145.3, J146.3, J147.3, R127.1, U19.C3
SDA19: J153.3, J154.3, J155.3, R134.1, U20.C3
SDA20: J161.3, J162.3, J163.3, R141.1, U21.C3
SDA21: J169.3, J170.3, J171.3, R148.1, U22.C3
SDA22: J177.3, J178.3, J179.3, R155.1, U23.C3
SDA23: J185.3, J186.3, J187.3, R162.1, U24.C3
VDDA: C1.1, J8.1, JP8.1, U1.B1, U1.B7
VDDA1: C3.1, J16.1, JP20.1, U2.B1, U2.B7
VDDA2: C6.1, J24.1, JP31.1, U3.B1, U3.B7
VDDA3: C8.1, J32.1, JP42.1, U4.B1, U4.B7
VDDA4: C10.1, J40.1, JP53.1, U5.B1, U5.B7
VDDA5: C12.1, J48.1, JP64.1, U6.B1, U6.B7
VDDA6: C14.1, J56.1, JP75.1, U7.B1, U7.B7
VDDA7: C16.1, J64.1, JP86.1, U8.B1, U8.B7
VDDA8: C18.1, J72.1, JP97.1, U9.B1, U9.B7
VDDA9: C20.1, J80.1, JP108.1, U10.B1, U10.B7
VDDA10: C22.1, J88.1, JP119.1, U11.B1, U11.B7
VDDA11: C24.1, J96.1, JP130.1, U12.B1, U12.B7
VDDA12: C26.1, J104.1, JP141.1, U13.B1, U13.B7
VDDA13: C28.1, J112.1, JP152.1, U14.B1, U14.B7
VDDA14: C30.1, J120.1, JP163.1, U15.B1, U15.B7
VDDA15: C32.1, J128.1, JP174.1, U16.B1, U16.B7
VDDA16: C34.1, J136.1, JP185.1, U17.B1, U17.B7
VDDA17: C36.1, J144.1, JP196.1, U18.B1, U18.B7
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

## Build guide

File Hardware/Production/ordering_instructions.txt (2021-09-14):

panel size, 169x117mm
PCB thickness, 1.6mm
number of layers, 2
soldermask color, Red
silkscreen color, White
oz copper, 1oz
finish, HASL lead free
stencils, none
pcs per panel, 24
min trace width, 0.1778mm / 0.0070in
min drill size, 0.3048mm / 0.0120in

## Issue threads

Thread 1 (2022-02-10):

Examples fail to run on ESP8266

jarkman, 2022-02-10:
I've just been trying to bring up Example1_DistanceArray with a VL53L5CX (https://www.sparkfun.com/products/18642) on an ESP8266 (a Wemos D1 Mini Pro).

I get something similar to the other forum participants trying to run this on ESP8266 in the thread at https://forum.sparkfun.com/viewtopic.php?p=231366, an endless reset loop with

ets Jan 8 2013,rst cause:2, boot mode:(3,6)

The ExceptionDecoder tool gives me the stack trace below. It suggests that readMultipleBytes is somehow running off the end of its buffer, but I can't see how that might happen.

Hope that helps, thanks!

Exception 3: LoadStoreError: Processor internal physical address or data error during load or store
PC: 0x40201524: SparkFun_VL53L5CX_IO::readMultipleBytes(unsigned short, unsigned char*, unsigned short) at /home/richard/Arduino/libraries/SparkFun_VL53L5CX_Arduino_Library/src/SparkFun_VL53L5CX_IO.cpp line 82
EXCVADDR: 0x4023b439

Decoding stack results
0x40201511: SparkFun_VL53L5CX_IO::readMultipleBytes(unsigned short, unsigned char*, unsigned short) at /home/richard/Arduino/libraries/SparkFun_VL53L5CX_Arduino_Library/src/SparkFun_VL53L5CX_IO.cpp line 82
0x40201460: SparkFun_VL53L5CX_IO::begin(unsigned char, TwoWire&) at /home/richard/Arduino/libraries/SparkFun_VL53L5CX_Arduino_Library/src/SparkFun_VL53L5CX_IO.cpp line 27
0x40201a26: _vl53l5cx_send_xtalk_data(VL53L5CX_Configuration*, uint8_t) at /home/richard/Arduino/libraries/SparkFun_VL53L5CX_Arduino_Library/src/vl53l5cx_api.cpp line 165
0x40202973: vl53l5cx_init(VL53L5CX_Configuration*) at /home/richard/Arduino/libraries/SparkFun_VL53L5CX_Arduino_Library/src/vl53l5cx_api.cpp line 318
0x40201438: SparkFun_VL53L5CX_IO::isConnected() at /home/richard/Arduino/libraries/SparkFun_VL53L5CX_Arduino_Library/src/SparkFun_VL53L5CX_IO.cpp line 34
0x40201460: SparkFun_VL53L5CX_IO::begin(unsigned char, TwoWire&) at /home/richard/Arduino/libraries/SparkFun_VL53L5CX_Arduino_Library/src/SparkFun_VL53L5CX_IO.cpp line 27
0x40202d54: Print::write(char const*) at /home/richard/.arduino15/packages/esp8266/hardware/esp8266/3.0.2/cores/esp8266/Print.h line 59
0x40201786: SparkFun_VL53L5CX::startRanging() at /home/richard/Arduino/libraries/SparkFun_VL53L5CX_Arduino_Library/src/SparkFun_VL53L5CX_Library.cpp line 220
0x40202fc8: Stream::readString() at /home/richard/.arduino15/packages/esp8266/hardware/esp8266/3.0.2/cores/esp8266/Stream.cpp line 248
0x402042c9: __pinMode(uint8_t, uint8_t) at /home/richard/.arduino15/packages/esp8266/hardware/esp8266/3.0.2/cores/esp8266/core_esp8266_wiring_digital.cpp line 39
0x402010ab: setup() at /tmp/arduino_modified_sketch_534223/Example1_DistanceArray.ino line 41
0x40203634: user_rf_pre_init() at /home/richard/.arduino15/packages/esp8266/hardware/esp8266/3.0.2/cores/esp8266/core_esp8266_phy.cpp line 353
0x40100db1: realloc(void*, size_t) at /home/richard/.arduino15/packages/esp8266/hardware/esp8266/3.0.2/cores/esp8266/umm_malloc/umm_malloc.cpp line 1113

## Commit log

2021-09-14 Add PROD_ID to IC
    [SparkFun Qwiic ToF Imager - VL53L5CX.brd, SparkFun Qwiic ToF Imager - VL53L5CX.sch]
2021-09-20 Add production files post design review
    [SparkFun Qwiic ToF Imager - VL53L5CX-Panel.brd, SparkFun Qwiic ToF Imager - VL53L5CX.brd, SparkFun Qwiic ToF Imager - VL53L5CX.sch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]
2021-11-04 Reduce copper and paste aperatures on VL53L5CX FP.
    [SparkFun Qwiic ToF Imager - VL53L5CX-Panel.brd, SparkFun Qwiic ToF Imager - VL53L5CX.brd, SparkFun Qwiic ToF Imager - VL53L5CX.sch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]
2021-11-18 Fix I2C address in schematic.
    [SparkFun Qwiic ToF Imager - VL53L5CX.sch]
2022-08-16 Add panel files for v1.1
    [SparkFun Qwiic ToF Imager - VL53L5CX-Panel.GBL, SparkFun Qwiic ToF Imager - VL53L5CX-Panel.GBP, SparkFun Qwiic ToF Imager - VL53L5CX-Panel.GBS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]

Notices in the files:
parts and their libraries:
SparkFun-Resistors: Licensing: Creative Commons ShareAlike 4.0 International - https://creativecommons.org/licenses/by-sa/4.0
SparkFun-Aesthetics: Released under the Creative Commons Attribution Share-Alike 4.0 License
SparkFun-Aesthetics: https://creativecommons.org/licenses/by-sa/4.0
